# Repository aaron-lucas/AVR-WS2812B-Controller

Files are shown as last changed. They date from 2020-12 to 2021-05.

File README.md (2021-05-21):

LED Strip Controller
==========================

Project Description:
---------------------
This project uses an Atmel ATtiny85 microcontroller to light up a strip of WS2812B LEDs with a set of 12 pre-defined patterns without relying on external libraries.

It is easy to create custom patterns as each LED is independently controlled.

A PCB design is included which allows the microcontroller and LED strip to be powered over a micro USB (type B) connection, with a toggle switch to turn the LED strip on or off and a Cherry-MX style button to cycle between the display modes.

Colors and Patterns:
---------------------

There are 12 pre-defined patterns programmed by default including 9 solid colors, an auto-cycle mode, disco mode and rainbow fade mode. The 9 pre-defined colors and their RGB hex values are as follows:

* Red               [0xC00000]
* Green             [0x206000]
* Purple            [0x6E00FF]
* Orange            [0xFF2000]
* Blue              [0x001080]
* White             [0x867565]
* Pink              [0xFF009A]
* Yellow            [0xEA5200]
* Light blue/cyan   [0x00777A]

Theoretically, some of these colors are inaccurate (e.g. the RGB combination for yellow is actually orange), however due to the different intensities of the individual red, green and blue LEDs, these color definitions show the correct color when displayed on the WS2812B LED strip.

**Auto-cycle mode** cycles through the above solid colors in order from top to bottom, showing each color for a pre-defined time interval (currently set to 7s).

**Disco mode** gives each LED a random color from the above list (excluding white), which changes every 25ms.

**Rainbow fade mode** slowly transitions all LEDS in a cycle from red to green to blue to red (and so on).

The modes are cycled in the order they are listed in above, starting from solid red. When the toggle button is pressed in rainbow fade mode, the pattern will cycle back around to solid red.

Limitations:
-------------
Since the LED colors are programmed without an external library, the communication with the LED strip is done using a custom function written in assembly which determines the correct signal timing by counting clock cycles. The number of clock cycles required to send the correct data has been tuned for a 16MHz clock frequency and therefore in order to display the correct colors, 16MHz is the only frequency which may be used.

Each LED is given its own memory location which defines the RGB color components and allows each LED to be set independently. However, since the ATtiny85 contains only 512 bytes of SRAM then the number of LEDs which can be controlled by this MCU is limited. The controller program utilises 20 bytes of data memory leaving 492 bytes for RGB data and stack memory. The minimum stack size required is approximately 22 bytes and the RGB data consists of 3 bytes per LED meaning a maximum of 156 LEDs can be controlled with the ATtiny85 - more would require a microcontroller with more SRAM. This is enough to control a 2m strip with 60LEDs/m (120 LEDs total) or a 5m strip with 30LEDs/m (150 LEDs total) which are both commonly found configurations.

Depending on the number of LEDs used and the pattern being displayed, the total current draw can exceed 2A which may exceed the safe limits of cheaper USB cables. It is recommended to use a cable with a high current rating.

Equipment Used:
----------------
* [Jaycar's 2M Addressable LED Strip](https://www.jaycar.com.au/2m-rgb-led-strip-with-120-x-addressable-w2812b-rgb-leds-arduino-mcu-compatible-5v/p/XC4390) 
* [ATtiny85 DIP8](https://www.microchip.com/wwwproducts/en/ATtiny85)
* [Jaycar's ISP Programmer (USBasp)](https://www.jaycar.com.au/isp-programmer-for-arduino-and-avr/p/XC4627)

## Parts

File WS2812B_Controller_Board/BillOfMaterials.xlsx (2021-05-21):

PCB Reference | Description | Package | Link
C1 | 0.1uF Capacitor | THT - Disc (Diameter: 4.3mm, Wdith: 1.9mm, Pitch: 5.0mm) | Generic
C2 | 10uF Capacitor | THT - Radial (Diameter: 5.0mm, Pitch: 2.0mm) | Generic
J1 | Micro-B USB connector, Amphenol 10103594-0001LF | SMD (5-pin) | https://au.mouser.com/ProductDetail/fci-amphenol/10103594-0001lf/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
J2 | N/A
MX1 | Cherry-MX style switch | THT - generic cherry switch | Generic
R1 | 10k resistor | THT - Axial (Length: 6.3mm, Diameter: 2.5mm, Pitch: 10.16mm) | Generic
R2 | Resistor (unspecified value) | THT - Axial (Length: 6.3mm, Diameter: 2.5mm, Pitch: 10.16mm) | Generic
R3 | 10k resistor | THT - Axial (Length: 6.3mm, Diameter: 2.5mm, Pitch: 10.16mm) | Generic
SW1 | SPDT toggle switch | THT - 3-pin Linear (Length: 12mm, Width: 7mm, Pitch: 4.5mm, Pin: 0.9mm x 2.1mm | https://www.jaycar.com.au/spdt-flattened-actuator-mini-toggle-switch/p/ST0546
U1 | ATtiny85 Microcontroller | THT - DIP8 | https://au.mouser.com/ProductDetail/microchip/attiny85-20pu/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
U1 | 8-pin DIP Mill-Max IC socket | THT - DIP8 | https://au.mouser.com/ProductDetail/mill-max/110-44-308-41-001000/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

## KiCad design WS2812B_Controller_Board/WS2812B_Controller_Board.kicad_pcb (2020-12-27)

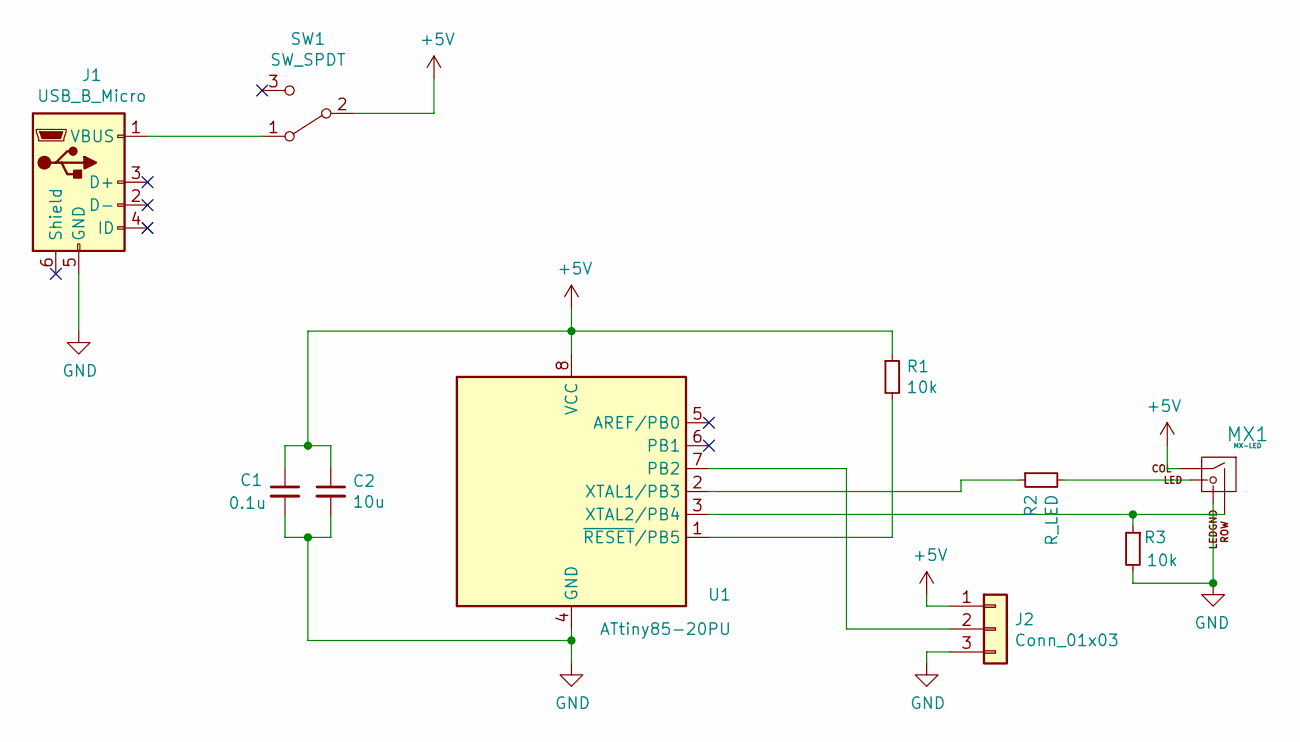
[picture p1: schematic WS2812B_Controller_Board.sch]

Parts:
C1: 0.1u; C_Disc_D4.3mm_W1.9mm_P5.00mm
C2: 10u; C_Radial_D5.0mm_H11.0mm_P2.00mm
J1: USB_B_Micro; USB_Micro-B_Amphenol_10103594-0001LF_Horizontal
J2: Conn_01x03; SolderWirePad_1x03_P3.175mm_Drill1mm
MX1: MX-LED; MX-1U
R1, R3: 10k; R_Axial_DIN0207_L6.3mm_D2.5mm_P10.16mm_Horizontal
R2: R_LED; R_Axial_DIN0207_L6.3mm_D2.5mm_P10.16mm_Horizontal
SW1: SW_SPDT; SPDT_Toggle_Switch_Jaycar_ST0546
U1: ATtiny85-20PU; DIP-8_W7.62mm

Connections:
+5V: C1.1, C2.1, J2.1, MX1.1 (COL), R1.1, SW1.2 (B), U1.8 (VCC)
GND: C1.2, C2.2, J1.5 (GND), J2.3, MX1.4 (LEDGND), R3.2, U1.4 (GND)
unnamed: J1.1 (VBUS), SW1.1 (A)
unnamed: J2.2, U1.7 (PB2)
unnamed: MX1.2 (ROW), R3.1, U1.3 (XTAL2/PB4)
unnamed: MX1.3 (LED), R2.2
unnamed: R1.2, U1.1 (~RESET~/PB5)
unnamed: R2.1, U1.2 (XTAL1/PB3)

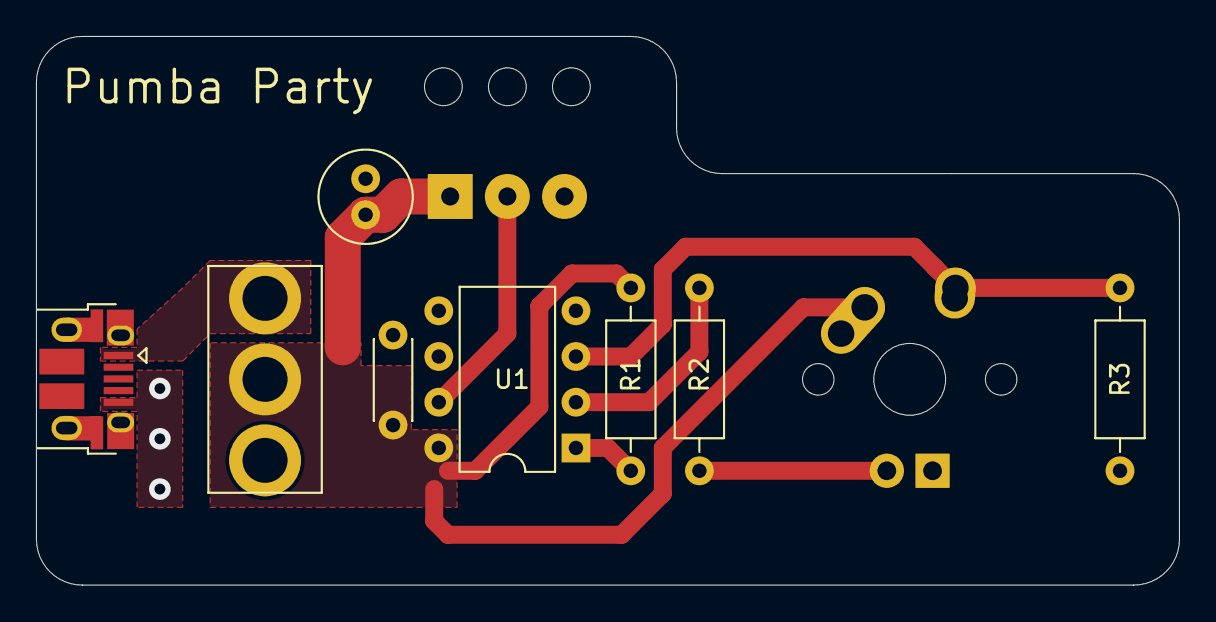
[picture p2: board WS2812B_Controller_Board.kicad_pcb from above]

Board: 2 copper layers, 63.5 x 30.5 mm, 10 parts (0 on the bottom side), 8 nets.

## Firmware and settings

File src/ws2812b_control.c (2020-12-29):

/* ============================================================================
 * LED Strip Controller - ATtiny85 MCU-based control of WS2812B LED Strips.
 *
 * main.c
 *
 * Created On: 2020/12/02
 *
 * Copyright (C) 2020  Aaron Lucas
 * 
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
 * aaronlucas98@gmail.com
 * https://github.com/aaron-lucas
 * ============================================================================
 */

#include <avr/io.h>
#include <avr/interrupt.h>
#include <util/delay.h>

#include "definitions.h"
#include "rgb_data.h"
#include "patterns.h"

// Setup functions
static void setup_gpio(void);
static void setup_pattern_timer(void);

// Function written in assembly to provide precise timings
extern void update_leds(struct rgb_data *colors);

// Collection of LED byte data
static struct rgb_data led_buffer[NUM_LEDS] = { 0 };
static inline void set_led(uint8_t led, enum color c) {
    led_buffer[led] = get_rgb(c);
}

static volatile enum pattern led_pattern;
static void show_next_pattern(void);

int main(void) {
    // Hardware setup
    cli();
    setup_gpio();
    setup_pattern_timer();
    sei();

    // Set initial state to first color in cycle
    led_pattern = FIRST_PATTERN;
    update_pattern(led_buffer, led_pattern, true);

    // Poll for buton press
    uint8_t btn_state_cur = 0, btn_state_prev = 0;
    while (1) {
        // Read current state and check for rising edge
        btn_state_cur = PINB & (1 << BUTTON_PIN);
        if (btn_state_cur && !btn_state_prev) {
            show_next_pattern();
        }
        btn_state_prev = btn_state_cur;

        // Debouncing delay
        _delay_ms(5);
    }
}

static void setup_gpio(void) {
    DDRB |= (1 << DATA_PIN);  // Set data pin to output

    DDRB &= ~(1 << BUTTON_PIN);  // Set button pin to input
    PORTB &= ~(1 << BUTTON_PIN); // Disable pull-up resistor
}

static void setup_pattern_timer(void) {
    // Interrupt every 10ms (100Hz)
    // 157 * 1024 / 16e6 = 10.048ms
    TCNT1 = 0;                              // Start counting from 0
    OCR1A = 157;                            // Counting to 157 takes 10ms
    OCR1C = OCR1A;                          // CTC mode uses OCR1C
    TIMSK |= (1 << OCIE1A);                 // Interrupt uses OCR1A
    TCCR1 |= ((1 << CTC1) | (0xB << CS10)); // CTC Mode with 1024x prescaler
}

static void show_next_pattern(void) {
    if (++led_pattern == NUM_PATTERNS) {
        led_pattern = FIRST_PATTERN;
    }

    // Cycle to next pattern, starting cycles from the start
    update_pattern(led_buffer, led_pattern, true);
}

ISR(TIMER1_COMPA_vect) {
    // Don't reset cycle patterns from the start
    update_pattern(led_buffer, led_pattern, false);
    update_leds(led_buffer);
}

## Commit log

2020-12-16 Add PCB design, save SREG in .S function
    [WS2812B_Controller_Board.kicad_pcb, WS2812B_Controller_Board.sch]
2020-12-27 Finish circuit board design
    [WS2812B_Controller_Board-B_Cu.gbr, WS2812B_Controller_Board-B_Mask.gbr, WS2812B_Controller_Board-B_SilkS.gbr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]
2020-12-29 Allow up to 156 LEDs to be used.
    Perform SRAM optimisations, update README and add debugging targets to Makefile.
2021-05-21 Clean up project, add BOM/footprints
    [BillOfMaterials.xlsx]

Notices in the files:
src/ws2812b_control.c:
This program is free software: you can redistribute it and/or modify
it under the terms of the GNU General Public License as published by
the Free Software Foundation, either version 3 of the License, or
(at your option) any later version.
